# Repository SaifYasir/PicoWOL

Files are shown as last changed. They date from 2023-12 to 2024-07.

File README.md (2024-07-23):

# PicoWOL

Rasberry Pi Pico to send WOL packets

This project provides both physical and remote means to wake up machines configured with wake-on-lan.

## Documentation
To generate documentation Doxygen must be installed, simply call doxygen in the root folder of this project and doxygen documentation will be generated.

## Third Party Dependencies
This project relies on [carlk3's](https://github.com/carlk3/no-OS-FatFS-SD-SPI-RPi-Pico) great work in creating an sd card library for the Rasberry Pi Pico.

## Aquiring Hardware
To see how to aquire required hardware see [readme](pcb_board/README.md).

## Usage

This program allows the picowol to turn machines on through [Wake-on-lan](https://en.wikipedia.org/wiki/Wake-on-LAN). Pico_WOL can either turn machines by using physical buttons on the device or sending a UDP packet (see ...) to the microcontroller's ip to turn the requested device on. The precompiled uf2 file sets External components to certain GPIO pins on the pico, these will be listed in case you wish not to buy a pcb.

- [Physical Buttons](#physical-buttons)
- [Micro SD Card Reader](#micro-sd-card-reader)
- [Display](#display)

### Physical Buttons

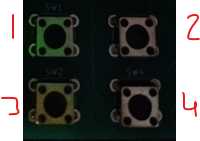
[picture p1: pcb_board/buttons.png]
Buttons for Pico Wake On Lan


The list below provides detail of what each button does and the mappings via GPIO to the Rasberry Pi Pico.

1. Allows the User to cycle between profiles, moving left. - GPIO 14
2. Provides basic information about the wireless pico, IP Address and the port in use (If you want to send packets to server) - GPIO 19
3. Allows the User to cycle between profiles, moving right. - GPIO 15
4. Wakes the selected profile. - GPIO 18

### Micro SD Card Reader

This reader is responsible in loading profiles and getting neccessary details to connect to the network.

#### Reading WiFi credentails

This program expects the file 'wifi_credentials.txt' to be at the base of the SD card in which will store the required credentials.
The credentials are seperated via semi colons and in the structure: SSID;SSID_PASSWORD i.e. VM112121;password123

#### Reading Wake On Lan Profiles

This program currently expects all profiles to be loaded in a singular file called 'wol_profiles.txt' which stores the name of the profile and its respective IP Address. 
The structure of storing profiles is as so: PROFILE_NAME;MACADDRESS ie gaming_pc;60ABDBA2A2A8.

Such that the file looks like this:

- Profile1;60ABDBA2A2A8
- Profile2;60ABDBA2A2A9
- Profile3;60ABDBA2A2AA

#### GPIO Connections

- SPI Chip Select - GPIO 13
- SPI RX - GPIO 12
- SPI TX - GPIO 11
- SPI SCK - GPIO 10

## Display

This display enables the user to view the currently selected profile.

The GPIO Mappings are as so:
- I2C_SDA - GPIO 16
- I2C_SCL - GPIO 17

## Potential future Improvements

This project was mainly a way for myself to learn more about microcontrollers and become more familiar with technologies like CMake and Doxygen.
However this program could do with a few improvements, mainly:

-   Wake on lan profile to be read across multiple files
-   Wake on lan profiles can be saved via UDP packets to Pico UDP server
-   Seperate Display from Pico Server, such that the server starts, even when the display is not initialised (working headless)

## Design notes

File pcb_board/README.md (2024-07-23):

# Hardware aquirement
This readme covers gathering relevant parts for the final build

## KiKad Project

This contains directory components gathered from my KiKad project, this should allow anyone to either grab gerber files needed for print or regenerate the gerber files needed.

## Case

I've created a STL file to hold both the display and the provided PCB Board, [here](case/case.stl).

## Build Components

Below is a list of components used to build the project:

- [Rasberry pi pico wireless (soldered heads)](https://www.amazon.co.uk/DVOZVO-Raspberry-Pre-Soldered-Wireless-Connectivity/dp/B0BV1H4D7M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)

- [M3 screws](https://www.amazon.co.uk/dp/B08J3KY5RM?psc=1&ref=ppx_yo2ov_dt_b_product_details)

- [M3 screw threads](https://www.amazon.co.uk/dp/B0CYH466PM?psc=1&ref=ppx_yo2ov_dt_b_product_details)

- [5V charging board](https://www.amazon.co.uk/dp/B09NX3QDKF?psc=1&ref=ppx_yo2ov_dt_b_product_details)

- [Lithium battery](https://www.amazon.co.uk/dp/B08ZCQXFX4?psc=1&ref=ppx_yo2ov_dt_b_product_details)

- [Boost converter (3.7v to 5v)](https://www.amazon.co.uk/dp/B0C3QLH284?psc=1&ref=ppx_yo2ov_dt_b_product_details)

- [Micro SD Card reader](https://www.amazon.co.uk/dp/B09YYG6BT3?psc=1&ref=ppx_yo2ov_dt_b_product_details)

- [LCD Display (1602 I2C)](https://www.amazon.co.uk/dp/B09YYG6BT3?psc=1&ref=ppx_yo2ov_dt_b_product_details)

- [100u Capacitor (any would do really)](https://www.amazon.co.uk/s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)

- Wire (Im guessing you can source this yourself)

## Final Look
This is roughly what the final design would look like, ignore any jerry rigging of wires, this was due to my own created errors.

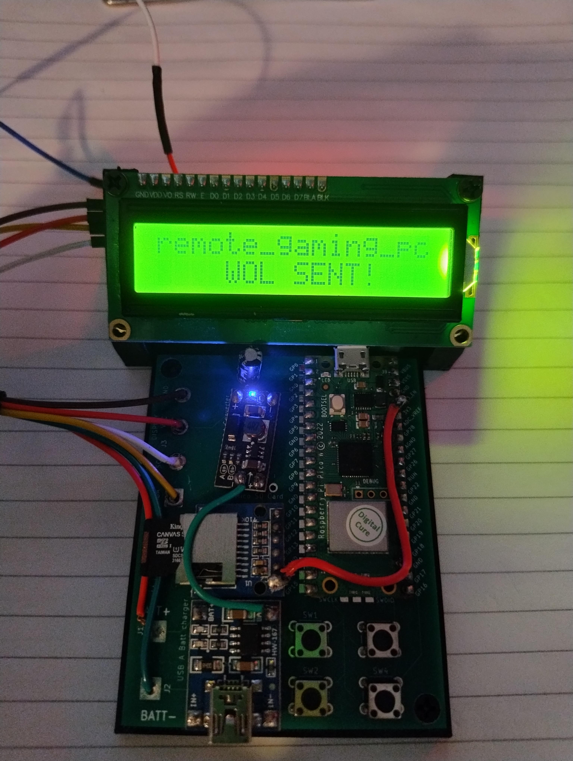
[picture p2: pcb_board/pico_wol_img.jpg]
Pico ready for Wake on Lan


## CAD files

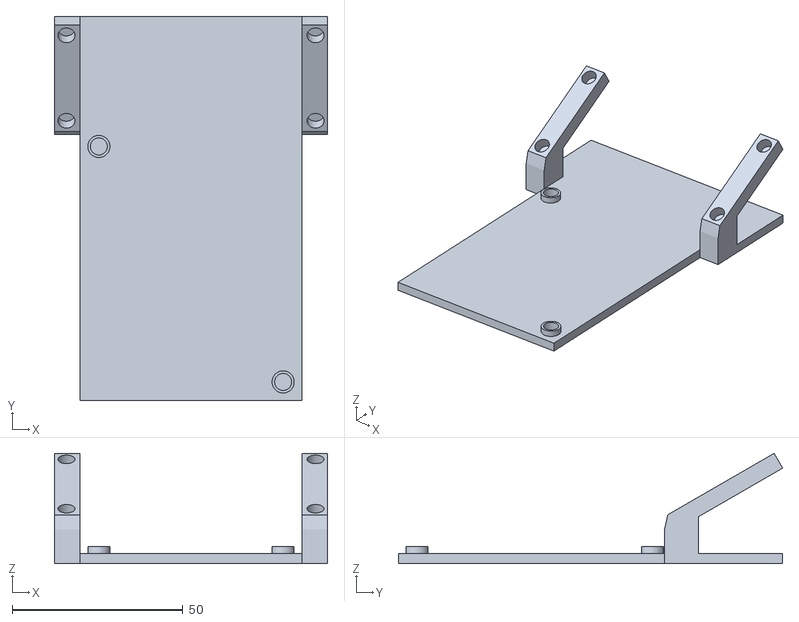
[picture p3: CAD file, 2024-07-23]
pcb_board/case/case.stl
80.0 x 112.6 x 32.3

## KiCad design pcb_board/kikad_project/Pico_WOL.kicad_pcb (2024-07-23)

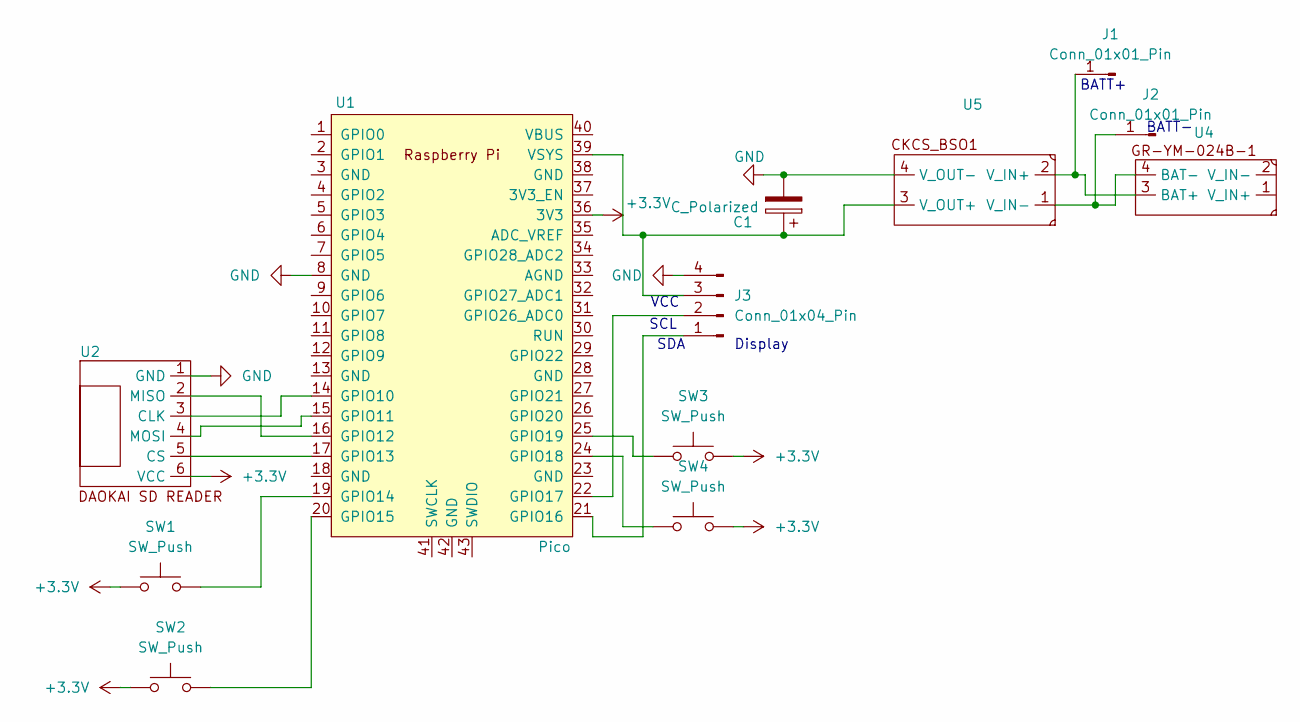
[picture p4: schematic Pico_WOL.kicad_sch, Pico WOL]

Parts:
C1: C_Polarized; CP_Radial_D5.0mm_P2.50mm
J1, J2: Conn_01x01_Pin; SolderWire-1.5sqmm_1x01_D1.7mm_OD3.9mm
J3: Conn_01x04_Pin; SolderWire-1.5sqmm_1x04_P7.8mm_D1.7mm_OD3.9mm
SW1, SW2, SW3, SW4: SW_Push; SW_PUSH_6mm
U1: Pico; RPi_Pico_SMD_TH
U2: Dokai_SD_READER
U4: USB_A_BATTERY_CHARGER
U5: boost_converter

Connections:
+3.3V: SW1.1, SW2.1, SW3.2, SW4.2, U1.36 (3V3), U2.6 (VCC)
GND: C1.2, J3.4, U1.8 (GND), U2.1 (GND), U5.4 (V_OUT-)
unnamed: J1.1, U4.3 (BAT+), U5.2 (V_IN+)
unnamed: J2.1, U4.4 (BAT-), U5.1 (V_IN-)
unnamed: J3.1, U1.21 (GPIO16)
unnamed: J3.2, U1.22 (GPIO17)
unnamed: C1.1, J3.3, U1.39 (VSYS), U5.3 (V_OUT+)
unnamed: U1.14 (GPIO10), U2.3 (CLK)
unnamed: U1.15 (GPIO11), U2.4 (MOSI)
unnamed: U1.16 (GPIO12), U2.2 (MISO)
unnamed: U1.17 (GPIO13), U2.5 (CS)
unnamed: SW1.2, U1.19 (GPIO14)
unnamed: SW2.2, U1.20 (GPIO15)
unnamed: SW4.1, U1.24 (GPIO18)
unnamed: SW3.1, U1.25 (GPIO19)

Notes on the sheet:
BATT-
SCL
VCC
Display
BATT+
SDA

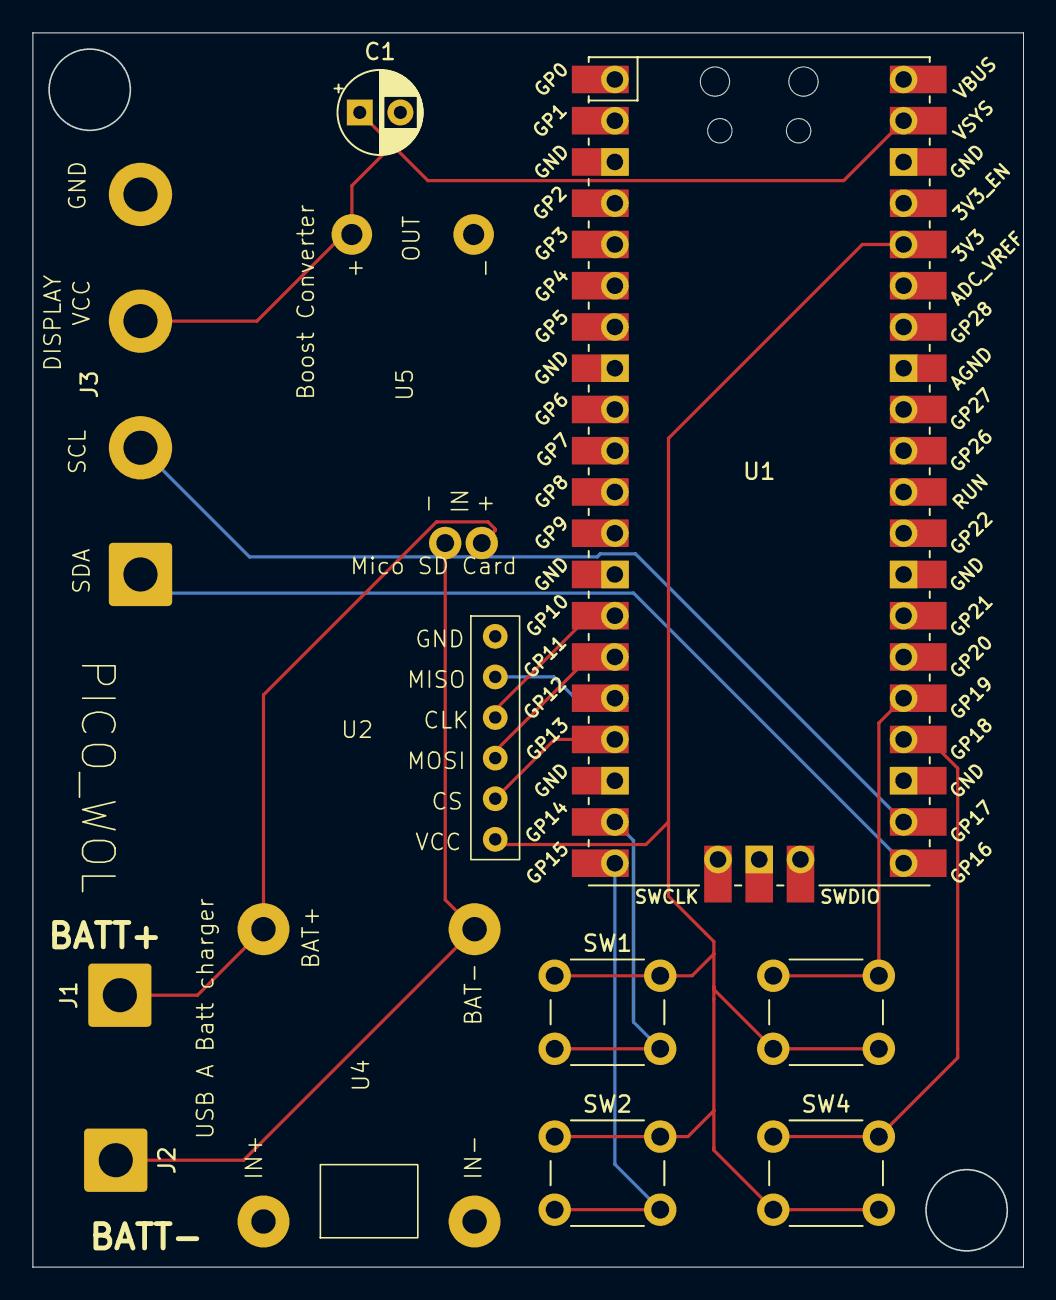
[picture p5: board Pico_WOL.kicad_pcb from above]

Board: 2 copper layers, 61.0 x 76.0 mm, 12 parts (0 on the bottom side), 15 nets.

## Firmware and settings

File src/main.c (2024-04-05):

#include <stdio.h>
#include <string.h>

#include "pico/stdlib.h"
#include "pico/cyw43_arch.h"
#include "pico/binary_info.h"
#include "pico/util/queue.h"

#include "hardware/i2c.h"
#include "hardware/gpio.h"
#include "hardware/spi.h"

#include "lwip/pbuf.h"
#include "lwip/udp.h"
#include "lwip/api.h"

#include "wol/wol.h"
#include "display/api/command.h"
#include "wifi/wifi.h"
#include "button/button.h"
#include "flash/flash.h"

/**
 * \brief The introduction message the display shows when starting the PICO
 * 
 */
char *INTRODUCTION_MSG[] = {"Pico","Wake On Lan"};

/**
 * \brief Main entry point to the program
 * 
 * Main starts and configures multiple components, such as the peripherals, wifi and running the server
*/
int main(){
    if(!stdio_init_all()){
        printf("Standard IO could not be initialised! \n");
    }
    if (cyw43_arch_init()) {
        printf("Wi-Fi initialisation failed! \n");
        return -1;
    }

    display_i2c_pico_init();
    display_i2c_lcd_init();

    // Tell user Pico is loading
    centre_send_message("Pico","Loading");

    //configure wol list
    initialise_sd_card();
    sd_card_read_and_initialise_wifi_credentials();

    if(start_wifi(default_wifi_credentials) != 0){
        printf("Connection to device failure, attempting again... \n");
        if(start_wifi(default_wifi_credentials) != 0){
            printf("Connection failed again, terminating! \n");
            return -1;
        }
    }

    //configure wol list
    sd_card_read_and_initialise_wol_profiles();

    initialise_all_buttons();
    disable_all_buttons();
    start_udp_server();

    // Show introduction message
    centre_send_message(INTRODUCTION_MSG[0],INTRODUCTION_MSG[1]);
    sleep_ms(1000);

    display_wol_profile(NULL);
    reenable_all_buttons();

    while(true){
        sleep_ms(1000);
        poll_udp_packets(&default_udp_polling_machine_stack);
    }

    clear_machine_stack(&default_wol_profiles);
}

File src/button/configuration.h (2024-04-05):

#pragma once

#include "hardware/gpio.h"

/**
 * \file configuration.h
 * \brief Defines hard set variables used for Physical button communication
*/

/**
 * \def LEFT_BTN_GPIO
 * GPIO pin for button to move left for the current profile selected on the display menu
 */
#define LEFT_BTN_GPIO       14
/**
 * \def RIGHT_BTN_GPIO
 * GPIO pin for button to move right for the current profile selected on the display menu
 */
#define RIGHT_BTN_GPIO      15
/**
 * \def ACCEPT_BTN_GPIO
 * GPIO pin for button to wake the currently selected device on the display menu
 */
#define ACCEPT_BTN_GPIO     18
/**
 * \def INFO_BTN_GPIO
 * GPIO pin for button to display information relating to wifi on the display screen
 */
#define INFO_BTN_GPIO       19 

/**
 * \def BTN_BEHAVIOUR_IRQ
 * GPIO pin for button to define behaviour of button (in this case power is passed through the buttons)
 */
#define BTN_BEHAVIOUR_IRQ   GPIO_IRQ_EDGE_RISE

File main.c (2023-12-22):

#include <stdio.h>
#include "pico/stdlib.h"
#include "pico/cyw43_arch.h"

int main(){
    stdio_init_all();
    if (cyw43_arch_init()) {
        printf("Wi-Fi init failed");
        return -1;
    }
    while (true) {
        cyw43_arch_gpio_put(CYW43_WL_GPIO_LED_PIN, 1);
        sleep_ms(250);
        cyw43_arch_gpio_put(CYW43_WL_GPIO_LED_PIN, 0);
        sleep_ms(250);
    }
}

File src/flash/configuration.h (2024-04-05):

#pragma once

#include "hardware/spi.h"

/**
 * \file configuration.h
 * \brief Defines hard set variables used for SPI communication and file identification
*/

/**
 * \def FLASH_SPI_INSTANCE
 * Defines the SPI instance used on the PICO, 
 * this instance is dependent on the GPIO Pins used
 */
#define FLASH_SPI_INSTANCE          spi1

/**
 * \def FLASH_SPI_CS_GPIO
 * SPI Chip Select GPIO pin
 */
#define FLASH_SPI_CS_GPIO           13
/**
 * \def FLASH_SPI_RX_GPIO
 * SPI RX GPIO pin or MISO pin
 */
#define FLASH_SPI_RX_GPIO           12
/**
 * \def FLASH_SPI_TX_GPIO
 * SPI TX GPIO PIN or MOSI pin
 */
#define FLASH_SPI_TX_GPIO           11
/**
 * \def FLASH_SPI_SCK_GPIO
 * SPI Clock GPIO pin
 */
#define FLASH_SPI_SCK_GPIO          10

/**
 * \def FLASH_SPI_BAUD_RATE
 * Baud rate set for communication between SD card and PICO
 */
#define FLASH_SPI_BAUD_RATE         200 * 1000

/**
 * \def FLASH_WIFI_FILENAME
 * File name used to identify file containing wifi configuration settings
 */
#define FLASH_WIFI_FILENAME         "wifi_credentials.txt"
/**
 * \def FLASH_WOL_FILENAME
 * File name used to identify file containing WOL profiles to load 
 */
#define FLASH_WOL_FILENAME          "wol_profiles.txt"
/**
 * \def FLASH_CSV_DELIMITER
 * Specifies the CSV limiter used
 */
#define FLASH_CSV_DELIMITER         ";\r\n"

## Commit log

2023-12-22 added basic implementation to blink pico_w LED pin
2023-12-25 added functionality for pico to interact with 16x2 display using I2C
    [configuration.h]
2024-01-01 adding wol functionality to pico
2024-01-03 adding functionality for buttons
    [configuration.h]
2024-01-17 comments editied & implemented configuration file for SD cards
    [configuration.h]
2024-01-22 Added configuration for SD cards (not yet implemented) aswell as adding additional functionality for WOL
    [configuration.h]
2024-01-28 added accept button and functionality to wake up a device
    [configuration.h]
2024-02-12 fixed commit issues
    [configuration.h]
2024-02-14 working on implementation of sd card
    [configuration.h]
2024-03-13 Moved UDP polling stack to a queue due to being threadsafe (therefore can be shared across both pico cores)
2024-03-16 Added additional functions ie getting ip to display
    [configuration.h]
2024-03-20 Added rudimentary server functionality to pico
2024-03-31 Reverted using queues back to locally defined stacks, due to only using 1 core
    [button.c, main.c, wifi.h]
2024-04-05 Added documentation
    [configuration.h]
2024-04-14 Added additional feature to notify user when SD card cannot be read on display
    [configuration.h]
2024-07-23 Added readmes and case/pcb files
    [Pico_WOL-B_Cu.gbr, Pico_WOL-B_Mask.gbr, Pico_WOL-B_Paste.gbr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]

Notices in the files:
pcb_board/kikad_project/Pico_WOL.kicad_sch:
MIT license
